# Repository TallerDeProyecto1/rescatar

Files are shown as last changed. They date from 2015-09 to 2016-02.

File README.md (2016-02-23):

# rescatAR
El presente proyecto pretende contribuir a disminuir la fatalidad en las rutas argentinas, mediante la integración de la tecnología GSM/GPRS, sensores de aceleración, giroscopios y la Computadora Industrial Abierta Argentina,  en un dispositivo capaz de determinar cuándo se produce un siniestro automovilístico que requiera la intervención de los servicios de asistencia médica y ser capaz de enviar un pedido de socorro.

##Objetivos
El objetivo primario del proyecto consiste en lograr que la CIAA recoja y analice datos de un acelerómetro para detectar colisiones automovilísticas,utilizando un módulo GSM/GPRS para poder reportar las mismas a los servicios de asistencia, contando con un conjunto de teclas y luces para la interacción con el usuario(como por ejemplo un botón de pánico y un botón para cancelar la alerta).
Paralelamente, se desarrolló una aplicación android que instalada en el teléfono que recibe el mensaje SMS de socorro muestra en un mapa interactivo la ubicación del accidente.
Al no poder disponer de un dispositivo GPS, se recurrió a simular  mediante coordenadas arbitrarias la ubicación del pedido de ayuda. No obstante, se pretende seguir avanzando con el proyecto y realizar las modificaciones necesarias para la incorporación de un módulo GPS que permita determinar con precisión la locación del siniestro automovilístico.

## Uso

El proyecto esta dividicdo en distintos modulos organizado en carpetas: 
* [Hardware](https://github.com/TallerDeProyecto1/rescatar/tree/master/Hardware)
* [Software](https://github.com/TallerDeProyecto1/rescatar/tree/master/Software)
* [Aplicacion Android](https://github.com/TallerDeProyecto1/rescatar/tree/master/RescatarApp) 

Cada modulo como se indica a continuacion se desarrolla con diferentes herramientas:

**Hardware**: Abarca los circuitos diseñados para regular la tension de alimentacion de los dispositivos para lo cual utilizo [KiCad](http://kicad-pcb.org/) en su version: (2013-jul-07)-stable

**Software**: El desarrollo del software que corre la edu-ciaa se se realizo utilizando la implementacion de OSEK del _proyecto ciaa_, cabe aclarar que se utilizo la version del firmware que reside en el branch [I2C](https://github.com/ciaa/Firmware/tree/i2c) de repositorio oficial del [proyecto-ciaa](http://www.proyecto-ciaa.com.ar/) debido a la utilizacion de este protocolo. 

**Aplicacion Android**:Se desarrollo con Android Studio version 1.5.0.

## Integrantes del grupo

Minig Traverso Marcelo

Garcia Manuel

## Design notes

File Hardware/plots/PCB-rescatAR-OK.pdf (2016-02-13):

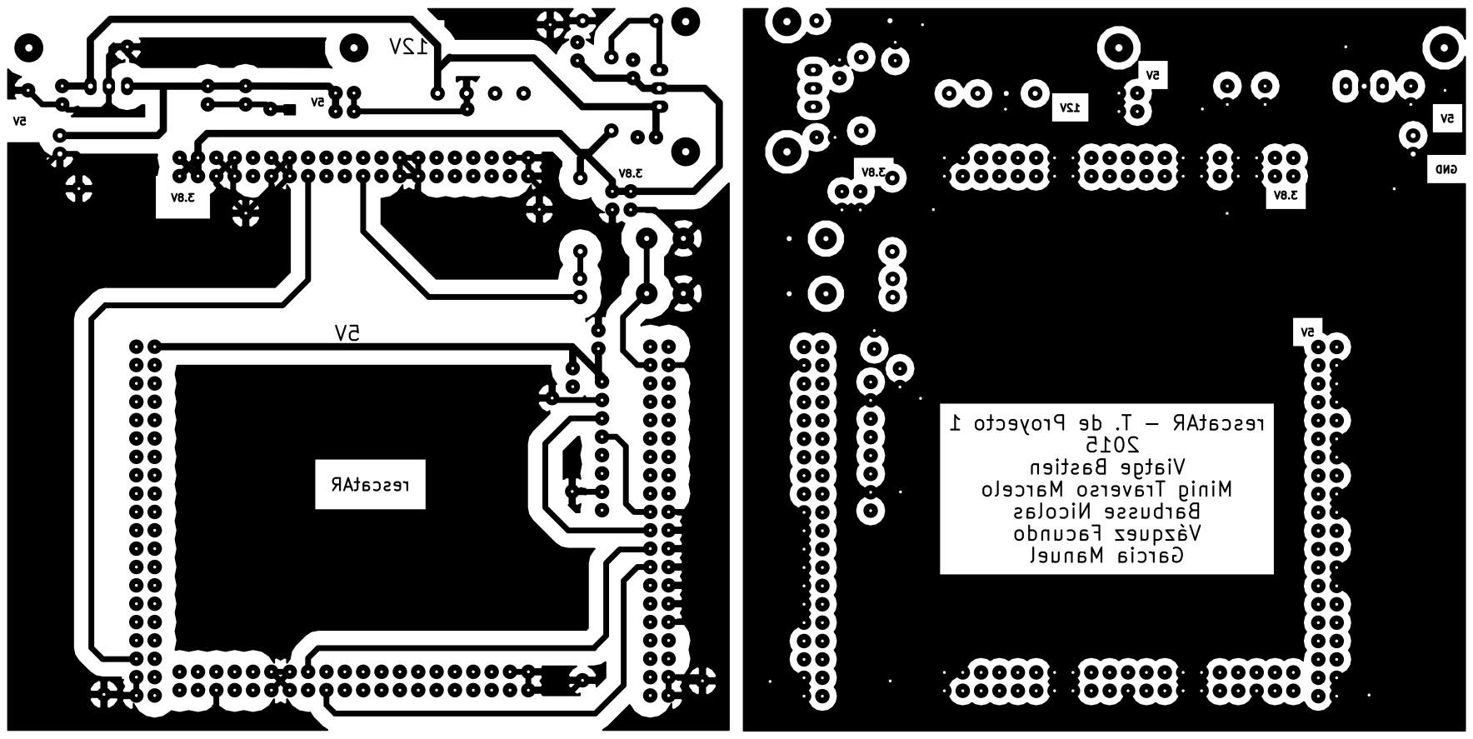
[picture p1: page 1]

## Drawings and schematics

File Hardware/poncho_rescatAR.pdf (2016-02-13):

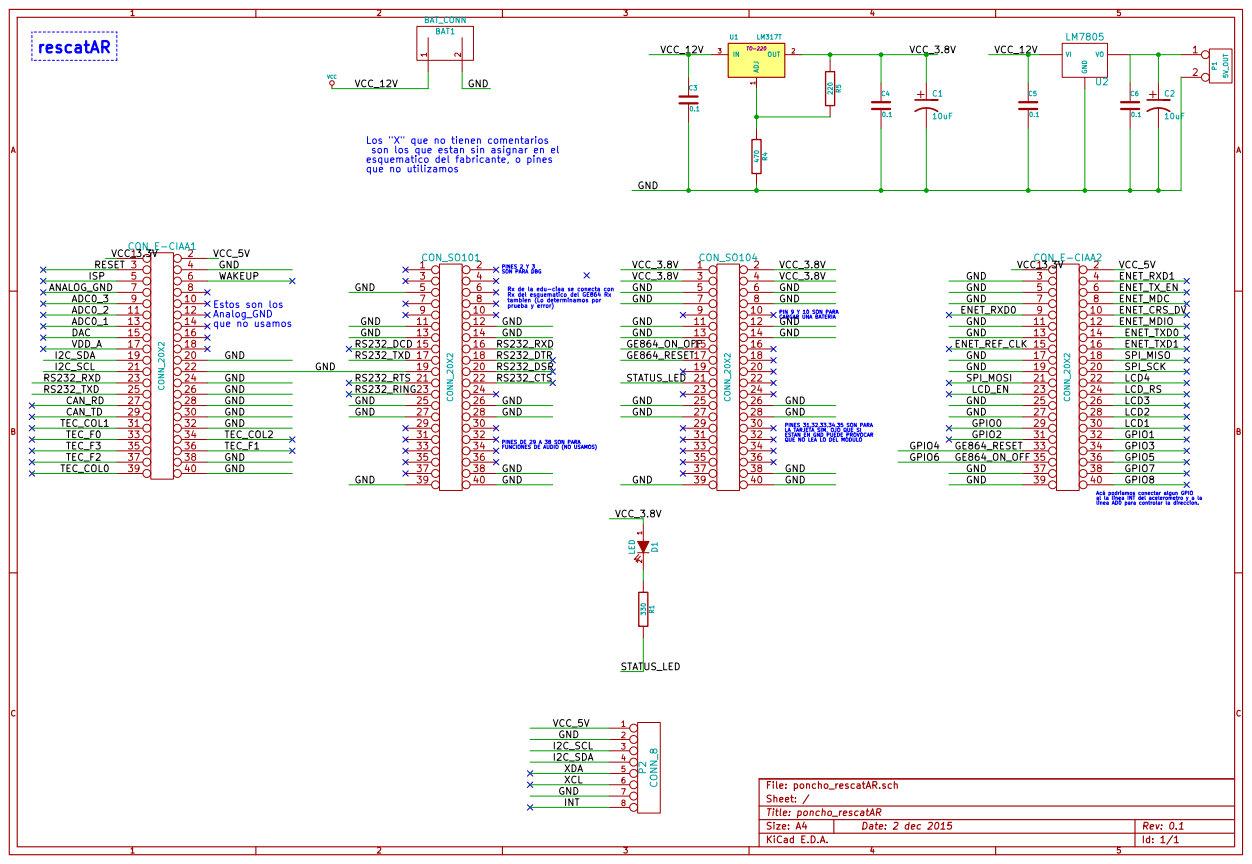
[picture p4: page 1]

linea AD0 para controlar la direccion. Rx de la edu-ciaa se conecta con Rx del esquematico del GE864 Rx
tambien (Lo determinamos por prueba y error)

Acá podriamos conectar algun GPIO
al la linea INT del acelerometro y a la

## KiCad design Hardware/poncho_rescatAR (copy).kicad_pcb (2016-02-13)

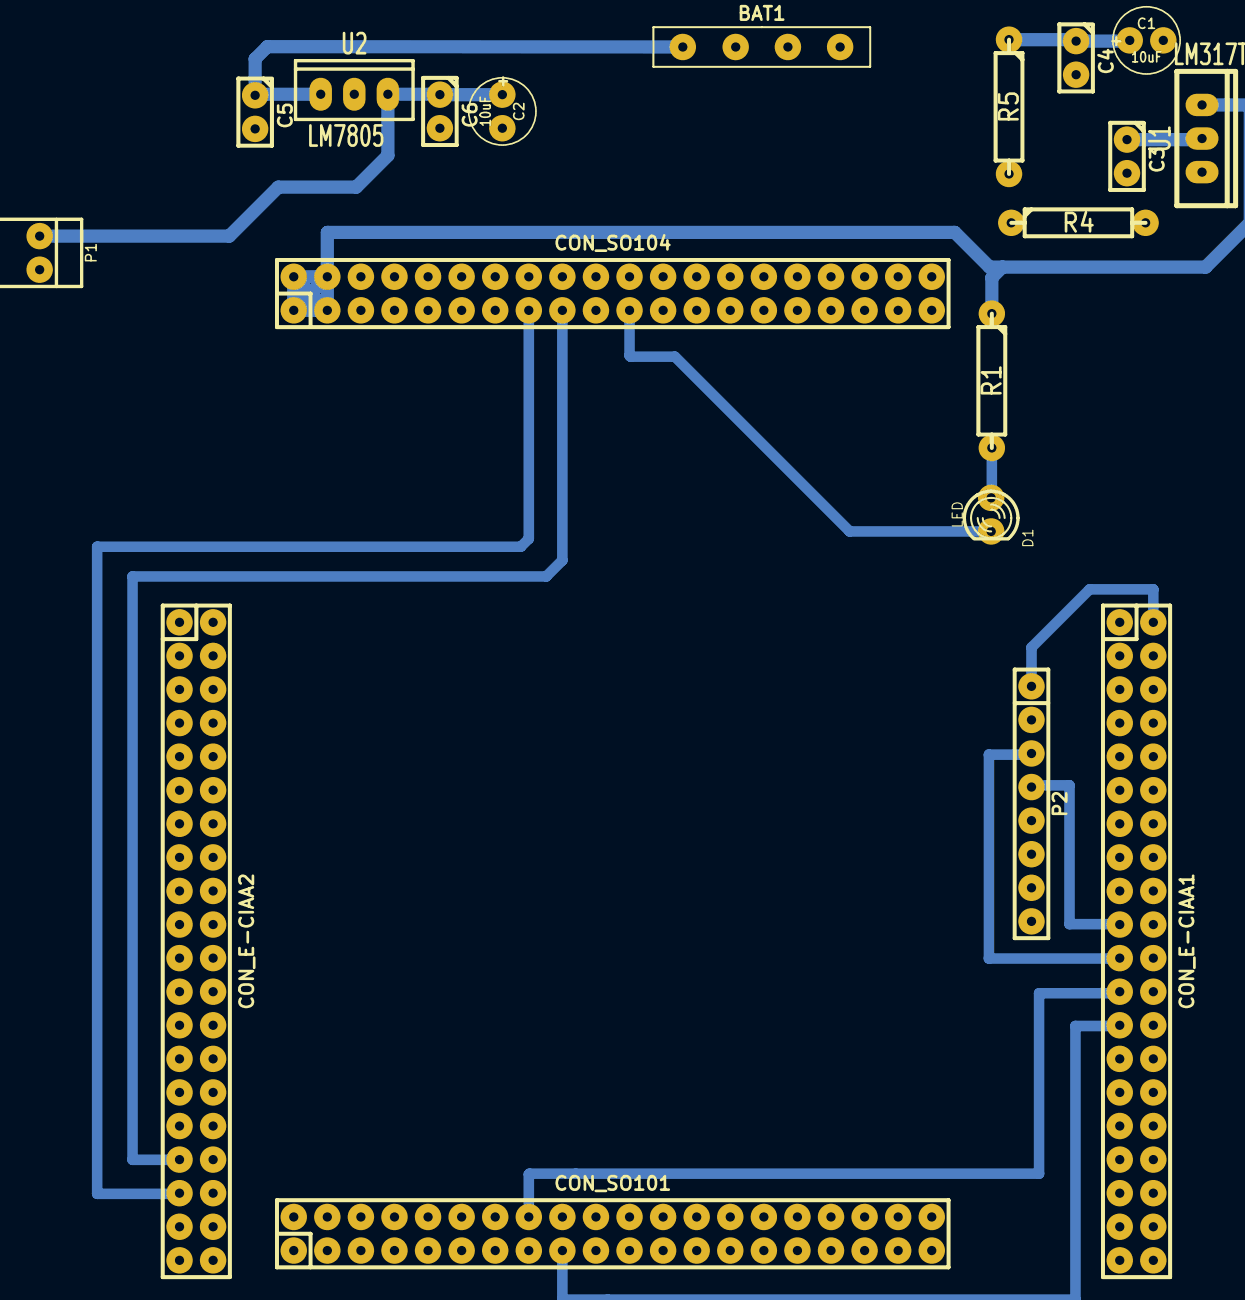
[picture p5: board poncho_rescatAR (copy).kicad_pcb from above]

Board: 2 copper layers, 19 parts (0 on the bottom side), 15 nets.

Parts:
BAT1: BAT_CONN; PIN_ARRAY_4x1
C1, C2: 10uF; C1V5
C3, C4, C5, C6: 0.1; C1
CON_E-CIAA1, CON_E-CIAA2: CONN_20X2; pin_strip_20x2
CON_SO101, CON_SO104: CONN_20X2; pin_strip_20x2
D1: LED; LED-3MM
P1: 5V_OUT; PINHEAD1-2
P2: CONN_8; pin_strip_8
R1: 330; R4-LARGE_PADS
R4: 470; R4-LARGE_PADS
R5: 220; R4-LARGE_PADS
U1: LM317T; TO220_VERT
U2: LM7805; LM78XXV

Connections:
/GE864_ON_OFF: CON_E-CIAA2.35, CON_SO104.15
/GE864_RESET: CON_E-CIAA2.33, CON_SO104.17
/GND: BAT1.2, C1.2, C2.2, C3.2, C4.2, C5.2, C6.2, CON_E-CIAA1.4, CON_E-CIAA1.20, CON_E-CIAA1.22, CON_E-CIAA1.24, CON_E-CIAA1.26, CON_E-CIAA1.28, CON_E-CIAA1.30, CON_E-CIAA1.32, CON_E-CIAA1.38, CON_E-CIAA1.40, CON_E-CIAA2.3, CON_E-CIAA2.5, CON_E-CIAA2.7, CON_E-CIAA2.11, CON_E-CIAA2.13, CON_E-CIAA2.17, CON_E-CIAA2.19, CON_E-CIAA2.25, CON_E-CIAA2.27, CON_E-CIAA2.37, CON_E-CIAA2.39, CON_SO101.5, CON_SO101.11, CON_SO101.12, CON_SO101.13, CON_SO101.14, CON_SO101.19, CON_SO101.25, CON_SO101.26, CON_SO101.27, CON_SO101.28, CON_SO101.38, CON_SO101.39, CON_SO101.40, CON_SO104.5, CON_SO104.6, CON_SO104.7, CON_SO104.8, CON_SO104.11, CON_SO104.12, CON_SO104.13, CON_SO104.14, CON_SO104.25, CON_SO104.26, CON_SO104.27, CON_SO104.28, CON_SO104.38, CON_SO104.39, CON_SO104.40, P1.2, P2.2, P2.7, R4.2, U2.GND
/I2C_SCL: CON_E-CIAA1.21, P2.3
/I2C_SDA: CON_E-CIAA1.19, P2.4
/RS232_RXD: CON_E-CIAA1.23, CON_SO101.16
/RS232_TXD: CON_E-CIAA1.25, CON_SO101.17
/STATUS_LED: CON_SO104.21, D1.2
/VCC_3.3V: CON_E-CIAA1.1, CON_E-CIAA2.1
/VCC_3.8V: C1.1, C4.1, CON_SO104.1, CON_SO104.2, CON_SO104.3, CON_SO104.4, R1.1, R5.1, U1.2
/VCC_5V: CON_E-CIAA1.2, CON_E-CIAA2.2, P2.1
unnamed: R4.1, R5.2, U1.1
unnamed: C2.1, C6.1, P1.1, U2.VO
unnamed: D1.1, R1.2
VCC: BAT1.1, C3.1, C5.1, U1.3, U2.VI

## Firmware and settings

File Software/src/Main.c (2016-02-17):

/*==================[inclusions]=============================================*/
#include "../inc/Main.h"    /* <= own header */

#include "os.h"               /* <= operating system header */
#include "ciaaI2CDevices.h"
#include "ciaaPOSIX_stdio.h"  /* <= device handler header */
#include "ciaaPOSIX_string.h" /* <= string header */
#include "ciaak.h"            /* <= ciaa kernel header */
#include "chip.h"
#include <stdlib.h>
#include <string.h>
#include <math.h>
#include "../../Rescatar/inc/MPU_6050.h"
#include "utime.h"	//no va creo


/*==================[macros and definitions]=================================*/
#define TEC1_MASK         0B0001
#define TEC2_MASK         0B0010
#define TEC3_MASK         0B0100
#define TEC4_MASK         0B1000
#define LEDS_RESET		  0B11100000
#define TICK			  10	//periodic task se ejecutara acada 10 milisegundos
#define X_ANGLEA_LARM	  45
#define Y_ANGLE_ALARM	  45
#define X_ACC_ALARM		  10
#define Y_ACC_ALARM		  10
#define TELIT_TIME_ON	  30



/*==================[internal data declaration]==============================*/

/* en esta estructura guardo las lecturas del MPU*/
MPU_data_struct MPU_data;

/* TODO reemplazar o reutilizar para cuando se implemente el telit
 * en num guardo el valor de los registros del giroscopio convertidos a string
 */
char num[]="    ";

/*TODO idem anterior. en message combino todos los strings generados en la lectura
 * de los ejes x,y,z
 */
char message[120];
char message2[120];
char numEmerg[15]="2346514794";
char chNumEmerg[30];

/*luces*/
uint8 outputs;

char systemOn=255;

/*determina el estado de emergencia*/
char alarma=0;

/*TODO esta variable debera ser eliminada cuando se implemente la comunicacion
 * serie con el telit, ya que se usa para determinar cada cuanto tiempo se deberan
 * mostrar  por terminal los valores
 */
char countSerial=0;

/*1 para enviar un mensaje por serial, 0 para recibir un menaje por serial
 */
char serialSend=0;

/*Se utiliza para llevar la cuenta regresiva ants de mandar el sms*/
char countAlarm=0;



/*==================[internal functions declaration]=========================*/

/*==================[internal data definition]===============================*/

/** \brief File descriptor for digital output ports
 *
 * Device path /dev/dio/out/0
 */
static int32_t fd_out;

/** \brief File descriptor for digital inputs ports
 *
 * Device path /dev/dio/in/0
 */
static int32_t fd_in;

/** \brief File descriptor for I2C
 *
 * Device path /dev/i2c/0
 */
static int32_t fd_i2c;

/** \brief File descriptor of the USB uart
 *
 * Device path /dev/serial/uart/1
 */
static int32_t fd_uart1;					//borrar, ya que solo sirve para debugear

/** \brief File descriptor of the uart
 *
 * Device path /dev/serial/uart/2
 */
static int32_t fd_uart2;




/*==================[external data definition]===============================*/

/*==================[internal functions definition]==========================*/

/*==================[external functions definition]==========================*/
/** \brief Main function
 *
 * This is the main entry point of the software.
 *
 * \returns 0
 *
 * \remarks This function never returns. Return value is only to avoid compiler
 *          warnings or errors.
 */
int main(void)
{
	/* Starts the operating system in the Application Mode 1 */
	/* This example has only one Application Mode */

	StartOS(AppMode1);

	/* StartOs shall never returns, but to avoid compiler warnings or errors
	 * 0 is returned */
	return 0;
}

/** \brief Error Hook function
 *
 * This fucntion is called from the os if an os interface (API) returns an
 * error. Is for debugging proposes. If called this function triggers a
 * ShutdownOs which ends in a while(1).
 *
 * The values:
 *    OSErrorGetServiceId
 *    OSErrorGetParam1
 *    OSErrorGetParam2
 *    OSErrorGetParam3
 *    OSErrorGetRet
 *
 * will provide you the interface, the input parameters and the returned value.
 * For more details see the OSEK specification:
 * http://portal.osek-vdx.org/files/pdf/specs/os223.pdf
 *
 */
void ErrorHook(void)
{
	ciaaPOSIX_printf("ErrorHook was called\n");
	ciaaPOSIX_printf("Service: %d, P1: %d, P2: %d, P3: %d, RET: %d\n", OSErrorGetServiceId(), OSErrorGetParam1(), OSErrorGetParam2(), OSErrorGetParam3(), OSErrorGetRet());
	ShutdownOS(0);
}

/** \brief Initial task
 *
 * This task is started automatically in the application mode 1.
 */
TASK(InitTask)
{
	/* init CIAA kernel and devices */
	ciaak_start();

	/* open UART connected to USB bridge (FT2232) */
	fd_uart1 = ciaaPOSIX_open("/dev/serial/uart/1", O_RDWR);				//borrar, sirve para debug
	/* open UART connected to RS232 */
	fd_uart2 = ciaaPOSIX_open("/dev/serial/uart/2", O_RDWR);

	//	/* change baud rate for uart usb */
	ciaaPOSIX_ioctl(fd_uart1, ciaaPOSIX_IOCTL_SET_BAUDRATE, (void *)ciaaBAUDRATE_115200);		//borrar, sirve para debug

	/* change baud rate for uart RS232  */
	ciaaPOSIX_ioctl(fd_uart2, ciaaPOSIX_IOCTL_SET_BAUDRATE, (void *)ciaaBAUDRATE_115200);

	//	/* change FIFO TRIGGER LEVEL for uart usb */
	ciaaPOSIX_ioctl(fd_uart1, ciaaPOSIX_IOCTL_SET_FIFO_TRIGGER_LEVEL, (void *)ciaaFIFO_TRIGGER_LEVEL3);						//borrar, sirve para debug

	/* change FIFO TRIGGER LEVEL for uart RS232 */
	ciaaPOSIX_ioctl(fd_uart2, ciaaPOSIX_IOCTL_SET_FIFO_TRIGGER_LEVEL, (void *)ciaaFIFO_TRIGGER_LEVEL3);

	/* Abro la comunicacion i2c (I2C0)*/
	fd_i2c = ciaaPOSIX_open("/dev/i2c/0", O_RDWR);

	/* seteamos el clockrate*/
	ciaaPOSIX_ioctl(fd_i2c, ciaaPOSIX_IOCTL_SET_CLOCKRATE, (void *)ciaaPOSIX_IOCTL_CLOCKRATE_400000);

	/* Configuramos la direccion del esclavo*/
	ciaaPOSIX_ioctl(fd_i2c, ciaaPOSIX_IOCTL_SET_SLAVEADD, (void *)MPU6050_ADDRESS);

	/* open CIAA digital outputs */
	fd_out = ciaaPOSIX_open("/dev/dio/out/0", O_RDWR);

	/* open CIAA digital inputs */
	fd_in = ciaaPOSIX_open("/dev/dio/in/0", O_RDWR);


	Chip_SCU_PinMux(6,10,MD_PUP,FUNC0); /* GPIO3[6], GPIO6 , p6_10*/
	Chip_GPIO_SetDir(LPC_GPIO_PORT, 3,(1<<6),1);	//seteo como salida
	Chip_GPIO_ClearValue(LPC_GPIO_PORT, 3,(1<<6));	//enciendo el telit


	/*se realizan las configuraciones iniciales del MPU*/
	MPU_6050_setup(fd_i2c,TICK);

	if(!MPU_6050_test(fd_i2c))
		ErrorHook();

	SetRelAlarm(ActivateTelitInitTask,1000, 1000);
	//	ActivateTask(TelitInitTask);


	/* terminate task */
	TerminateTask();
}

/** \brief Periodic Task
 *
 * This task is started automatically every time that the alarm
 * ActivatePeriodicTask expires.
 *
 */
TASK(PeriodicTask)
{
	/* actualizo los angulos de posicion y las aceleraciones*/
	MPU_6050_update(fd_i2c,&MPU_data);


	/* activacion de la alarma si se supera (en modulo) en los ejes 'x' o 'y' a los
	 * valores maximos en cualquier sentido, si la aceleracion lateral supera (en modulo)
	 * los valores maximos o si se produce una desaceleracion brusca en el eje y. ademas
	 * se inicia countAlarm para realizar la cuenta regresiva antes de mandar el mensaje
	 * ademas el booleando serialSend se pone en 1 para indicar que se debe envia un mensaje
	 */
	if((((abs(MPU_data.xgyro)>X_ANGLEA_LARM)|(abs(MPU_data.ygyro)>Y_ANGLE_ALARM))|((MPU_data.yacc<-Y_ACC_ALARM)|(abs(MPU_data.xacc)>X_ACC_ALARM)))&&alarma!=1&&systemOn==255){
		alarma=1;
		countAlarm=0;
	}

	/*
	 * control de las luces y de la cuenta regresiva para mandar el mensaje
	 */
	if(alarma!=0){
		if((++countAlarm>(1000/TICK)) & (outputs!= 0x3f)){
			outputs=outputs | (outputs >> 1 ) ;
			countAlarm=0;
		}
		/* si se cumple este if, se llego al final de la cuenta y se debe mandar
		 * el mensaje de auxilio*/
		if(outputs== 255){
			CancelAlarm(ActivatePeriodicTask);
			CancelAlarm(ActivateKeysTask);
			serialSend=1;
			//			ActivateTask(SerialEchoTask);
			/*
			 * Aca debo configurar el mensaje a enviar por sms, y luego activar la
			 * serial task
			 */

			/* Activates the SerialEchoTask task */
			ActivateTask(TelitSMSTask);
		}
	}
	ciaaPOSIX_write(fd_out, &outputs, 1);
	TerminateTask();
}

/** \brief Keys Task
 *
 * This task is started automatically every time that the alarm
 * ActivateKeysTask expires.
 *
 */
TASK(KeysTask)
{
	static uint8_t stateKeys;
	uint8_t inputs;
	uint8_t edgeUpKeys;

	/* read input keys */
	ciaaPOSIX_read(fd_in, &inputs, 1);

	/* detects edges*/
	edgeUpKeys = (inputs ^ stateKeys) & inputs;

	/* save new state of keys */
	stateKeys = inputs;

	/* TEC1: Boton para cancelar la alarma*/
	if (TEC1_MASK & edgeUpKeys)
	{
		alarma=0;
		outputs =LEDS_RESET;
		ciaaPOSIX_write(fd_out, &outputs, 1);
	}

	/* TEC2: boton de panico para activar la alarma
	 *  */
	if (TEC2_MASK & edgeUpKeys)
	{
		if(systemOn!=0){
			alarma=1;
			countAlarm=0;
			serialSend=1;
		}
	}

	/* TEC3: cambiar numero */
	if (TEC3_MASK & edgeUpKeys)
	{
		CancelAlarm(ActivatePeriodicTask);
		CancelAlarm(ActivateKeysTask);
		serialSend=0;
		outputs=0b11001000;
		ciaaPOSIX_write(fd_out, &outputs, 1);
		ActivateTask(TelitSMSTask);
	}

	/* TEC4: toogle systemOn */
	if (TEC4_MASK & edgeUpKeys)
	{
		systemOn=~systemOn;
		if(systemOn==0){
			outputs=0b11010000;
			ciaaPOSIX_write(fd_out, &outputs, 1);
		}else
			outputs =LEDS_RESET;
	}

	/* terminate task */
	TerminateTask();
}

TASK(ListenTelitTask){
	outputs=~outputs;
	ciaaPOSIX_write(fd_out, &outputs, 1);
	//Esta tarea se encarga de leer lo que envia el telit y activa eventos
	ciaaPOSIX_read(fd_uart2,message2, 50);
	strcat(message,message2);
	//ciaaPOSIX_write(fd_uart1, message, ciaaPOSIX_strlen(message));
	//	char str[15]=strstr(message,"CNE:")
	//	if((str!=NULL)){
	//		numEmerg=str
	//	}
	if((strstr(message,"OK")!=NULL)){
		CancelAlarm(ActivateListenTelitTask);
		TaskStateType state=4;
		GetTaskState(TelitSMSTask,&state);
		if(WAITING	== state){//Si TelitSMSTask esta en estado waiting entonces
			if(serialSend==0){//Si tenemos que leer los mensajes recibidos
				if(strstr(message,"CNE")!=NULL){//Si el msj contiene la palabra clave "CNE" se recibio un msj que pretende cambiar el numero
					int count=4,indice=strlen(message); //llendo desde el "OK hacia el inicio del mensaje deberian haber 4 /n, asi guardamos solo el mensaje y no todo el eco"
					while(count>0){
						if(message[--indice]=='\n'){
							--count;
						}
					}
					int i;
					indice++;
					for(i=indice;i<strlen(message);i++)
					{
						if(message[i]!='\r'){
							chNumEmerg[i-indice]=message[i];
						}else{
							chNumEmerg[i-indice]=0;
							break;
						}
					}
					SetEvent(TelitSMSTask,EventOK);
				}else{
					SetEvent(TelitSMSTask,EventErrorCode);
				}
			}else
				SetEvent(TelitSMSTask,EventOK);
		}else{
			SetEvent(TelitInitTask,EventOK);
		}
		memset(message, 0, sizeof(message));//Limpiar el msj total cuando encuentra la condicion
	}else if ((strstr(message,">")!=NULL)){
		memset(message, 0, sizeof(message));//Limpiar el msj total cuando encuentra la condicion
		CancelAlarm(ActivateListenTelitTask);
		SetEvent(TelitSMSTask,EventPromt);
	}else if ((strstr(message,"ERROR")!=NULL)){
		memset(message, 0, sizeof(message));//Limpiar el msj total cuando encuentra la condicion
		CancelAlarm(ActivateListenTelitTask);
		SetEvent(TelitSMSTask,EventErrorCode);
		//	}else if ((strstr(message,"CMGS:")!=NULL)){
		//		CancelAlarm(ActivateListenTelitTask);
		//		SetEvent(TelitSMSTask,EventSMSSend);
	}

	memset(message2, 0, sizeof(message2));
	ciaaPOSIX_write(fd_out, &outputs, 1);
	TerminateTask();
}

TASK(TelitInitTask)
{
	static char countTelit=TELIT_TIME_ON;

	outputs=~outputs;
	ciaaPOSIX_write(fd_out, &outputs, 1);
	if(countTelit--==0){
		ciaaPOSIX_write(fd_out, &outputs, 1);
		CancelAlarm(ActivateTelitInitTask);
		strcpy(message,"AT+CMGF=1\r\n");
		ciaaPOSIX_write(fd_uart2, message, ciaaPOSIX_strlen(message));
		memset(message, 0, sizeof(message));
		SetRelAlarm(ActivateListenTelitTask,999,500);
		WaitEvent(EventOK);
		ClearEvent(EventOK);
		strcpy(message,"AT+COPS=0\r\n");
		ciaaPOSIX_write(fd_uart2, message, ciaaPOSIX_strlen(message));
		memset(message, 0, sizeof(message));
		SetRelAlarm(ActivateListenTelitTask,1000,200);
		WaitEvent(EventOK);
		ClearEvent(EventOK);
		strcpy(message,"AT+FCLASS=0\r\n");
		ciaaPOSIX_write(fd_uart2, message, ciaaPOSIX_strlen(message));
		memset(message, 0, sizeof(message));
		SetRelAlarm(ActivateListenTelitTask,1000,500);
		WaitEvent(EventOK);
		ClearEvent(EventOK);
		strcpy(message,"AT+CMGD=1,4\r\n");									//borra sms en la sim
		ciaaPOSIX_write(fd_uart2, message, ciaaPOSIX_strlen(message));
		memset(message, 0, sizeof(message));
		SetRelAlarm(ActivateListenTelitTask,1000,500);
		WaitEvent(EventOK);
		ClearEvent(EventOK);
		/* activate periodic task:
		 *  - for the first time after 1000 ticks (1000 ms)
		 *  - and then every tick ticks (definido como macro)
		 */
		SetRelAlarm(ActivatePeriodicTask, 1000, TICK);
		SetRelAlarm(ActivateKeysTask, 50, 50);
		outputs=LEDS_RESET;
	}
	TerminateTask();
}


/*
 * Esto se usa para debuguear y ver los valores. se deberia implementar aca la
 * comunicacion serie con el modulo telit
 */
TASK(TelitSMSTask)
//Esta tarea se encarga de escribir en el telit y esperar por los eventos
{
	EventMaskType Events;
	if(serialSend==1){
		strcpy(message,"AT+CMGS=\"");
		strcat(message,numEmerg);
		strcat(message,"\"\r\n");
		ciaaPOSIX_write(fd_uart2, message, ciaaPOSIX_strlen(message));
		memset(message, 0, sizeof(message));
		SetRelAlarm(ActivateListenTelitTask,1000,500);
		WaitEvent(EventPromt);
		ClearEvent(EventPromt);
		char alarm[]="Rescatar\nHH:mm:SS\n-30.9064706\n-47.9420838";
		int leng=ciaaPOSIX_strlen(alarm);
		alarm[leng]=0x1A;
		alarm[leng+1]=0;
		ciaaPOSIX_write(fd_uart2, alarm, ciaaPOSIX_strlen(alarm));
		memset(message, 0, sizeof(message));
		SetRelAlarm(ActivateListenTelitTask,8000,1000);
		/*
		 * El problema esta aca, si lo hacemos con breakpoints funciona! :)
		 * POr eso lo dejamos que espere 8segundos
		 * */
		WaitEvent(EventOK);
		ClearEvent(EventOK);
		outputs=0b11010000;
		ciaaPOSIX_write(fd_out, &outputs, 1);
		alarma=0;
		systemOn=0;
	}else
		if(serialSend==0){
			strcpy(message,"AT+CMGR=1\r\n");//Para leer el primer mensaje
			ciaaPOSIX_write(fd_uart2, message, ciaaPOSIX_strlen(message));
			memset(message, 0, sizeof(message));
			SetRelAlarm(ActivateListenTelitTask,8000,1000);
			WaitEvent(EventOK | EventErrorCode);
			GetEvent(TelitSMSTask, &Events);
			ClearEvent(Events);
			if (Events & EventOK) {
				//ANALIZAR chNumEmerg
				//Tiene "CNE" hay que cambiarlo
				if((strstr(chNumEmerg,"CNE")!=NULL)){
					//Si cumple la condicion de la HASH
					int i=0;
					while (chNumEmerg[i]!=','){
						numEmerg[i]=chNumEmerg[i];//CAMBIAR numEmerg
						i++;
					}
				}
				outputs=LEDS_RESET;
			}
			else{
				outputs=0b11010000;
			}
			ciaaPOSIX_write(fd_out, &outputs, 1);

			/*
			 * FORMATO DEL MSJ RECIBIDO PARA CAMBIR EL NUMERO DE EMERGENCIA:
			 * "NNNNNNNNNN,PASSWORD,CNE" PASSWORD SERA UN NUMERO CALCULADO
			 *  MEDIANTE UNA FUNCION HASH DEPENDIENTE DE "NNNNNNNNNN" (NUMERO
			 *  QUE SE DESEA SETEAR)
			 */

			/*
			if(serialSend==0){
			strcpy(message2,"AT+CMGR=1\r\n");
			ciaaPOSIX_write(fd_uart2, message2, ciaaPOSIX_strlen(message2));
			memset(message, 0, sizeof(message));
			ciaaPOSIX_read(fd_uart2,message2, 180);
			ciaaPOSIX_write(fd_uart1, message, ciaaPOSIX_strlen(message));
			while((strstr(message2,"OK")==NULL) && (strstr(message2,"+CMS ERROR: 321")==NULL)){		//321 no hay mensajes recibidos
				memset(message, 0, sizeof(message));
				ciaaPOSIX_read(fd_uart2,message2, 180);
				ciaaPOSIX_write(fd_uart1, message, ciaaPOSIX_strlen(message));
			}
			 */


		}
	SetRelAlarm(ActivatePeriodicTask, 1000, TICK);
	SetRelAlarm(ActivateKeysTask, 50, 50);
	TerminateTask();
}


/*
 * PROBLEMAS
 * -- la calibracion deberia hacerse despues de 30 ms(pag * 12 del datashet)
 * -- el boton cancelar deberia llamar a una recalibracion? si cancelo con los angulos
 * de posicion superancdo los limites se va a volver a llamar la alarma
 */

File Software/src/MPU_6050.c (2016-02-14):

///*==================[inclusions]=============================================*/
#include "../../Rescatar/inc/MPU_6050.h"

#include "ciaak.h"            /* <= ciaa kernel header */
#include <math.h>			//para arcotg en filtro

/*==================[macros]=================================================*/

#define GRAV 		9.81
#define PESO 		0.95
#define RADAGRA 	57.3   			// 180/pi
#define PHI 		3.141592

/*==================[internal data declaration]==============================*/

/*en esta estructura guardo los offset luego de la calibracion*/
static MPU_data_struct MPU_data_offset;
/*dt almacena el delta tiempo (en ms) segun el cual se toman las muestras*/
static float dt;
/* en esta estructura guardo las lecturas del MPU*/
static MPU_data_struct MPU_data;



/*==================[external functions definition]==========================*/


uint8_t  MPU_6050_readReg(int32_t	fd_i2c,uint8_t RegAddress,uint8_t *data){
	ciaaPOSIX_write(fd_i2c,&RegAddress,1);/*
	 * Escribir Register Address de donde queremos leer, tener en
	 * cuenta que el metodo "ciaaPOSIX_write" ya de por si realiza
	 * una escritura en el bus de la add del slave. (Ver secuencia en pagina 36/52 del datasheet del MPU6050)
	 * */
	ciaaPOSIX_read(fd_i2c,data,1);/*Leer el dato :)*/
	return *data;
}

uint8_t  MPU_6050_writeReg(int32_t	fd_i2c,uint8_t RegAddress,uint8_t data){
	uint8_t datos[]={RegAddress,data};//Cargar arreglo con direccion y dato a escribir
	ciaaPOSIX_write(fd_i2c,datos,2);//LLamar a escribir, tener en cuenta que lo hace en dos pasos,(Ver secuencia en pagina 36/52 del datasheet del MPU6050)
	return 0;
}

uint8_t  MPU_6050_test(int32_t fd_i2c){
	/*sirve para almacenar temporalmente los valores de los registros que contienen
	 *datos de 8bits
	 */
	uint8_t data;

	MPU_6050_readReg (fd_i2c,MPU6050_RA_WHO_AM_I,&data);
	if(data!=0x68)
		return (0);
	return 1;
}


uint8_t  MPU_6050_update(int32_t	fd_i2c,MPU_data_struct *datos){
	/*sirve para almacenar temporalmente los valores de los registros que contienen
	 *datos de 16bits
	 */
	int16_t data_word;

	/*sirve para almacenar temporalmente los valores de los registros que contienen
	 *datos de 8bits
	 */
	uint8_t data_byte;

	/*sirve para almacenar temporalmente las direcciones a pasar como parametro de los
	 * registros que deberan ser leidos
	 */
	uint8_t regAdress;

	regAdress=MPU6050_RA_INT_STATUS;
	MPU_6050_readReg(fd_i2c,regAdress,&data_byte);
	if((data_byte & 0b00000001) ==1){
		/*
		 * lectura y escalamiento del registro x del acelerometro
		 */
		regAdress=MPU6050_RA_ACCEL_XOUT_H;
		MPU_6050_readReg(fd_i2c,regAdress,&data_byte);
		data_word=(int16_t)((data_byte<<8)&0xff00);
		++regAdress;
		MPU_6050_readReg(fd_i2c,regAdress,&data_byte);
		data_word=((data_word | data_byte)+MPU_data_offset.xacc);
		MPU_data.xacc=((float)data_word)/(INT16_MAX/AFS_SEL);
		MPU_data.xacc=MPU_data.xacc*GRAV;

		/*
		 * lectura y escalamiento del registro y del acelerometro
		 */
		regAdress=MPU6050_RA_ACCEL_YOUT_H;
		MPU_6050_readReg(fd_i2c,regAdress,&data_byte);
		data_word=(int16_t)((data_byte<<8)&0xff00);
		++regAdress;
		MPU_6050_readReg(fd_i2c,regAdress,&data_byte);
		data_word=((data_word | data_byte)+MPU_data_offset.yacc);
		MPU_data.yacc=((float)data_word)/(INT16_MAX/AFS_SEL);
		MPU_data.yacc=MPU_data.yacc*GRAV;

		/*
		 * lectura y escalamiento del registro z del acelerometro
		 */
		regAdress=MPU6050_RA_ACCEL_ZOUT_H;
		MPU_6050_readReg(fd_i2c,regAdress,&data_byte);
		data_word=(int16_t)((data_byte<<8)&0xff00);
		++regAdress;
		MPU_6050_readReg(fd_i2c,regAdress,&data_byte);
		data_word=((data_word | data_byte)+MPU_data_offset.zacc);
		MPU_data.zacc=((float)data_word)/(INT16_MAX/AFS_SEL);
		MPU_data.zacc=(MPU_data.zacc)*GRAV;

		/*
		 * lectura del registro x del giroscopio
		 */
		regAdress=MPU6050_RA_GYRO_XOUT_H;
		MPU_6050_readReg(fd_i2c,regAdress,&data_byte);
		data_word=(int16_t)((data_byte<<8)&0xff00);
		++regAdress;
		MPU_6050_readReg(fd_i2c,regAdress,&data_byte);
		data_word=(data_word | data_byte)+MPU_data_offset.xgyro;

		//filtro y escalamiento del registro x del giroscopio

		MPU_data.xgyro=PESO*((((float)data_word/(INT16_MAX/FS_SEL)))*dt+MPU_data.xgyro)+(1-PESO)*atan(MPU_data.yacc/(sqrt(pow(MPU_data.xacc,2)+pow(MPU_data.zacc,2))))*(float)RADAGRA;

		/*
		 * lectura del registro y del giroscopio
		 */
		regAdress=MPU6050_RA_GYRO_YOUT_H;
		MPU_6050_readReg(fd_i2c,regAdress,&data_byte);
		data_word=(int16_t)((data_byte<<8)&0xff00);
		++regAdress;
		MPU_6050_readReg(fd_i2c,regAdress,&data_byte);
		data_word=(data_word | data_byte)+MPU_data_offset.ygyro;

		//filtro y escalamiento del registro y del giroscopio
		MPU_data.ygyro=PESO*((((float)data_word/(INT16_MAX/FS_SEL)))*dt+MPU_data.ygyro)-(1-PESO)*atan(MPU_data.xacc/(sqrt(pow(MPU_data.yacc,2)+pow(MPU_data.zacc,2))))*(float)RADAGRA;

		/*
		 * lectura y escalamiento del registro z del giroscopio
		 */
		regAdress=MPU6050_RA_GYRO_ZOUT_H;
		MPU_6050_readReg(fd_i2c,regAdress,&data_byte);
		data_word=(int16_t)((data_byte<<8)&0xff00);
		++regAdress;
		MPU_6050_readReg(fd_i2c,regAdress,&data_byte);
		data_word=(data_word | data_byte)+MPU_data_offset.zgyro;
		MPU_data.zgyro+=(((float)data_word/(INT16_MAX/FS_SEL)))*dt;

		//filtro registro z debe ser implementado de otra forma

		*datos=MPU_data;
		return 1;
	}
	return 0;
}
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

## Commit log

2015-09-17 add schematic gy-521 (breakout board MPU6050)
2015-10-09 Primer commit del esquematico del poncho
    [poncho_rescatAR.sch]
2015-10-09 arreglo error de alimentacion del acelerometro
    [poncho_rescatAR.sch]
2015-10-29 Arreglos en base a los hablado con el profesor
    [poncho_rescatAR.sch]
2015-10-30 Agregue los encabezados de los metodos del modulo GSM
2015-11-04 cambio conector del MPU en el esquematico
    [poncho_rescatAR.sch]
2015-11-04 simplificacion del esquematico y comienzo del PCB
    [poncho_rescatAR.sch]
2015-11-10 cambios en el esquematico con el regulador de tension para el modulo telit, y el zocalo para la bateria
    [poncho_rescatAR.dsn, poncho_rescatAR.kicad_pcb, poncho_rescatAR.sch]
2015-12-02 retoques finales al esquemetico y pcb base
    [$poncho_rescatAR.sch, poncho_rescatAR.kicad_pcb, poncho_rescatAR.sch]
2015-12-02 perfeccionando el pcb
    [poncho_rescatAR.kicad_pcb]
2015-12-03 mas retoques al pcb, consideracion del boton de reset y los disipadores
    [poncho_rescatAR.kicad_pcb]
2015-12-03 Agregado de capacitores en la alimentacion del acelerometro y pulsador de reset de la ciaa
    [$poncho_rescatAR.sch, poncho_rescatAR (copy).kicad_pcb, poncho_rescatAR.sch]
2015-12-03 que la aplicacion Rescatar sea !
    y la aplicacion fue.
    (para instalarla, pueden poner el app-debug.apk en el telefono pero solo
    puede andar correcto con una version de android mas baja que la 4.3 !)
2015-12-04 retoques al pcb, cambio por el footprint erroneo del LM317
    [poncho_rescatAR.kicad_pcb]
2015-12-04 retoques para prueba final
    [poncho_rescatAR.kicad_pcb]
2015-12-04 rotoques pcb
    [poncho_rescatAR.kicad_pcb]
2015-12-05 Correccion error en PCB y creacion de pdf para tranferir al cobre
    [poncho_rescatAR.kicad_pcb]
2015-12-06 retoques al PCB, agregado de disipadores
    [poncho_rescatAR.kicad_pcb]
2016-01-21 Modificaciones finales al pcb
    [poncho_rescatAR.kicad_pcb]
2016-02-13 Cambio de la clave personal para usar google maps en la app
2016-02-17 ultimos cambios menor en el Software, interfaz luminica y demas
